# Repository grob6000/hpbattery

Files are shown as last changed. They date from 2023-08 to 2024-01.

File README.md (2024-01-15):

# HP Battery

## UPDATED PROJECT

**Please see my new project page at [github.com/calcpsu/cphp82001](https://github.com/calcpsu/cphp82001)**

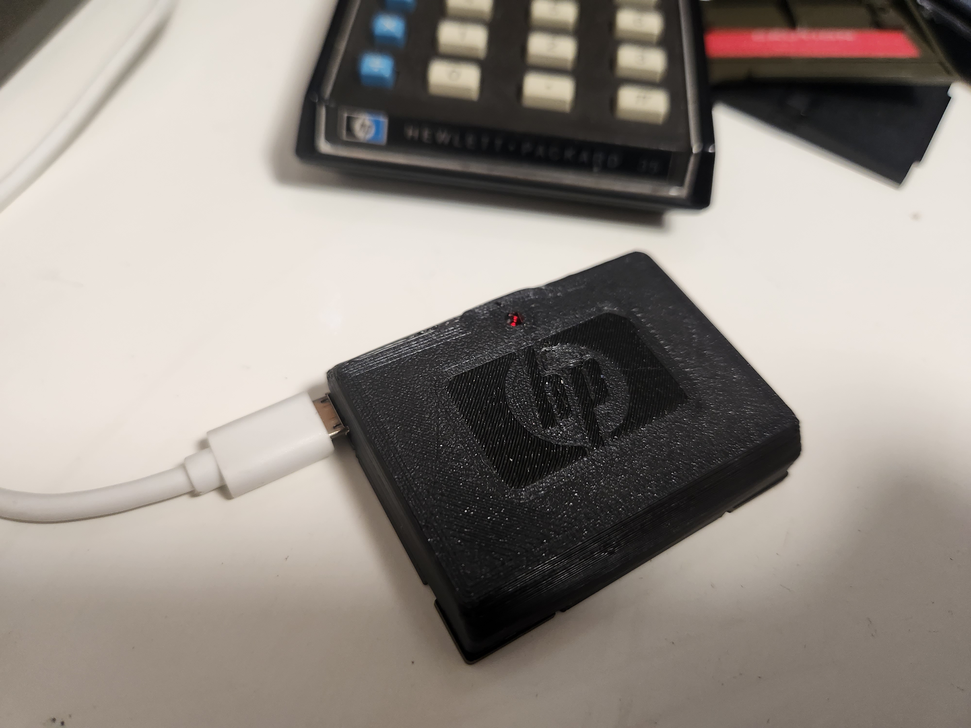
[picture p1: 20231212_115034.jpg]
Photo of prototype battery


A Li-Po battery replacement design for HP35/HP45/HP55/HP65/HP67 calculators. The original batteries had ~ 500mAh capacity, while modern Ni-MH replacements are typically ~1500mAh.

While a higher capacity is not necessarily feasible, Li-Po has the advantage of far reduced self-discharge in comparison to Ni-MH, which is an advantage for an intermittently-used device.

Ni-MH / Ni-CD batteries are notorious for leaking, which is somewhat traded-off against the notoriety of Li-Pos to self-immolate.

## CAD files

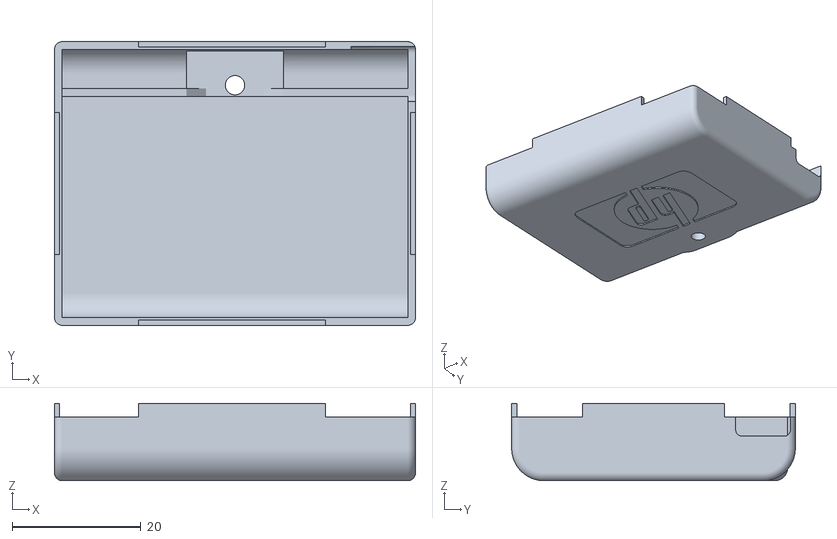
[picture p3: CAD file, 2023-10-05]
hpbatterycase_05_HP.stl
56.0 x 44.0 x 12.0

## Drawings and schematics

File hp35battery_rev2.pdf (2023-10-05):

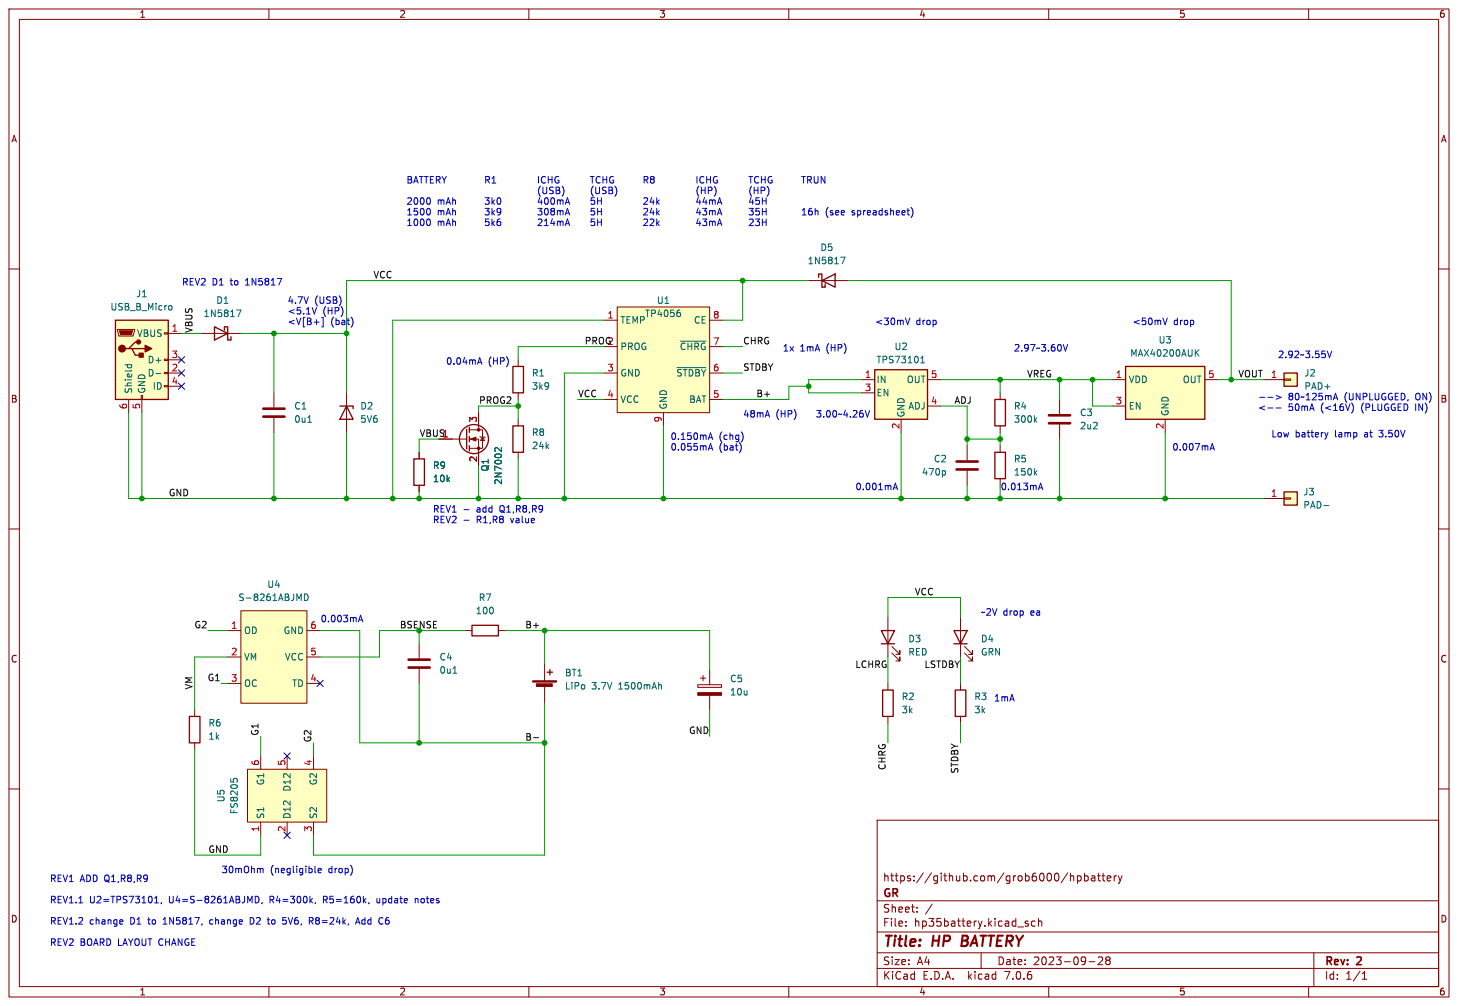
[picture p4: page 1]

BATTERY R1 ICHG TCHG R8 ICHG TCHG TRUN
(USB) (USB) (HP) (HP) 2000 mAh 3k0 400mA 5H 24k 44mA 45H
VREG CHRG
ADJ VCC

Low battery lamp at 3.50V

https://github.com/grob6000/hpbattery
File: hp35battery.kicad_sch Sheet: / GR

Id: 1/1 Title: HP BATTERY

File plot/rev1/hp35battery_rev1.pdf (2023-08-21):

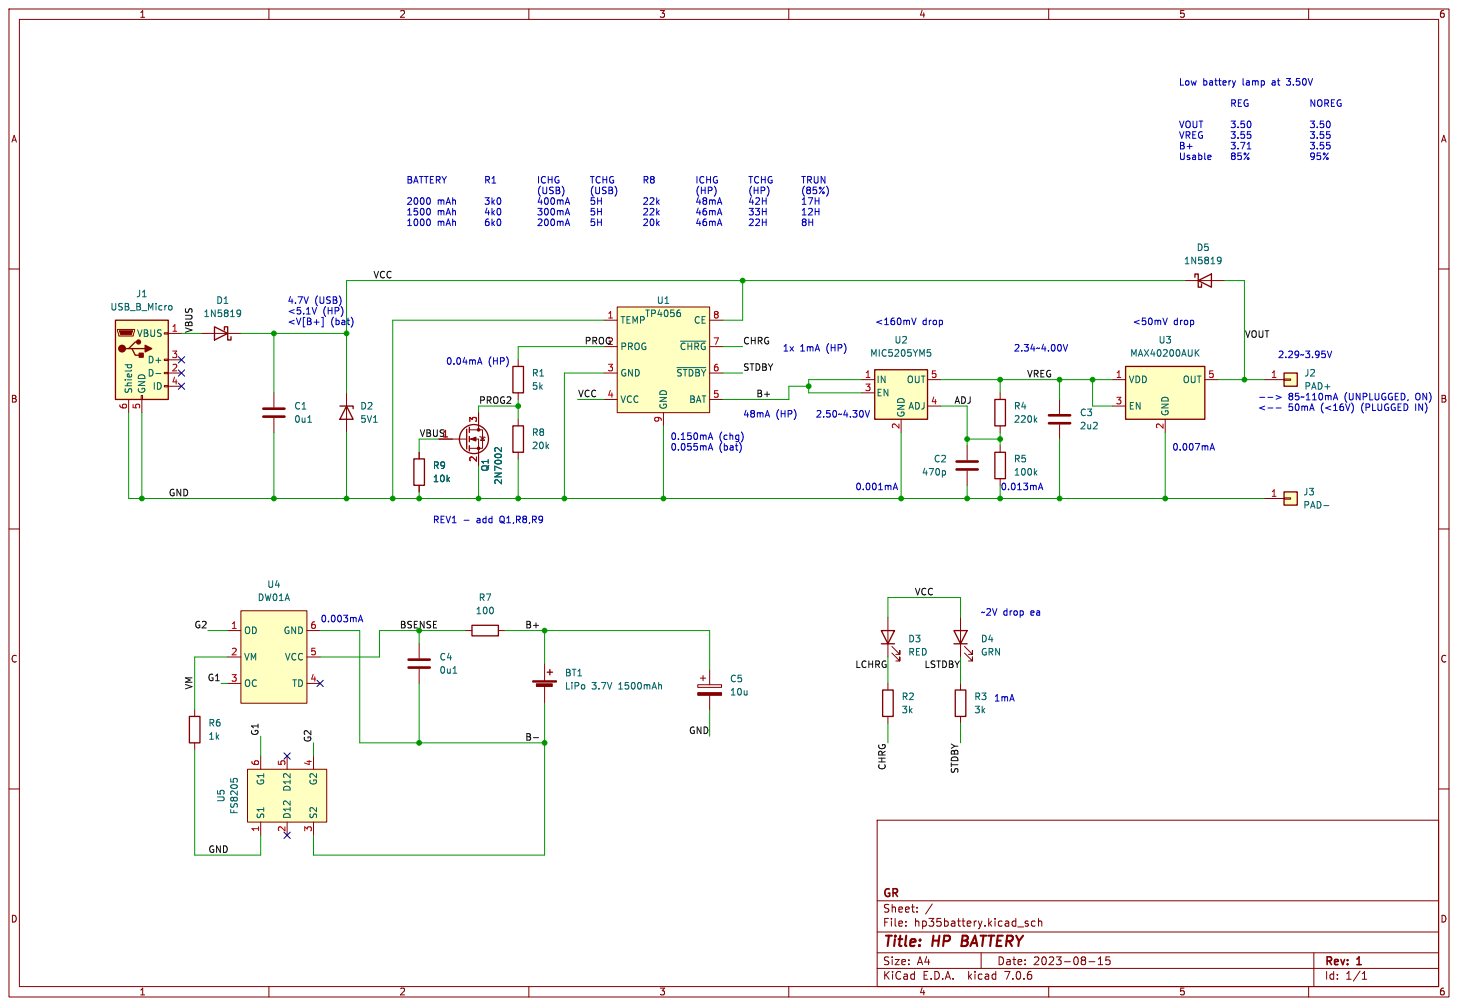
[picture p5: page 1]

Low battery lamp at 3.50V REG NOREG

0.04mA (HP) BATTERY R1 ICHG TCHG R8 ICHG TCHG TRUN
(USB) (USB) (HP) (HP) (85%) 2000 mAh 3k0 400mA 5H 22k 48mA 42H 17H

9 U1 TP4056 D3 RED OD 1 VM 2 OC 3 TD 4 VCC 5 GND 6 U4 DW01A

Id: 1/1 Title: HP BATTERY

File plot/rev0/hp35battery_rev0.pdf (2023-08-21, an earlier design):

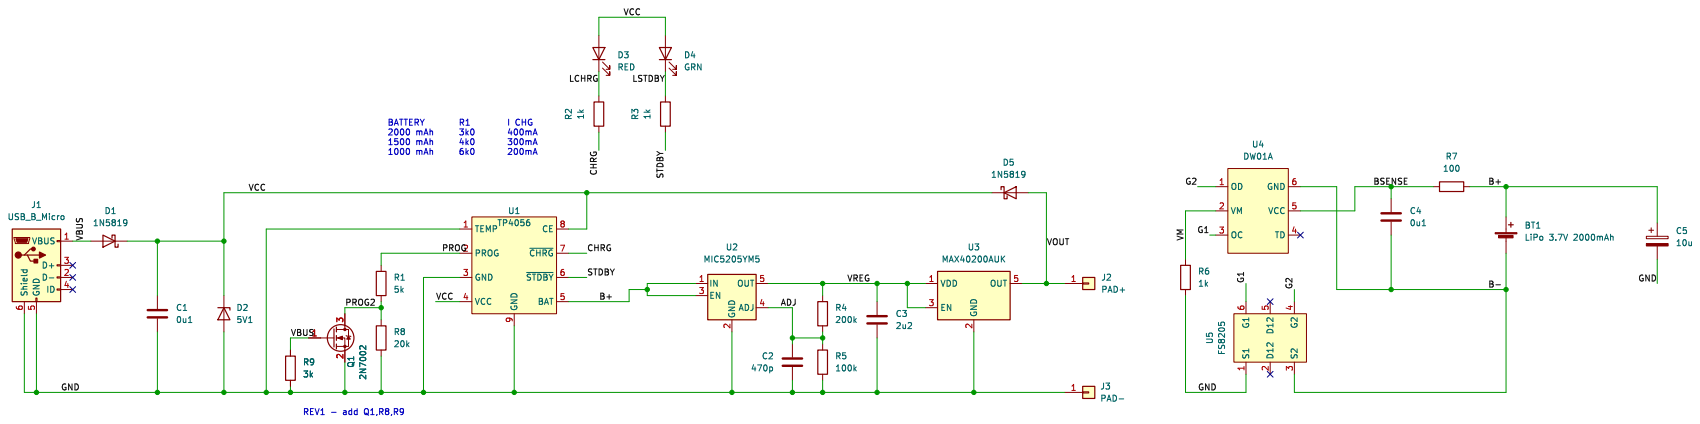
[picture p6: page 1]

Id: 1/1 Title: HP BATTERY

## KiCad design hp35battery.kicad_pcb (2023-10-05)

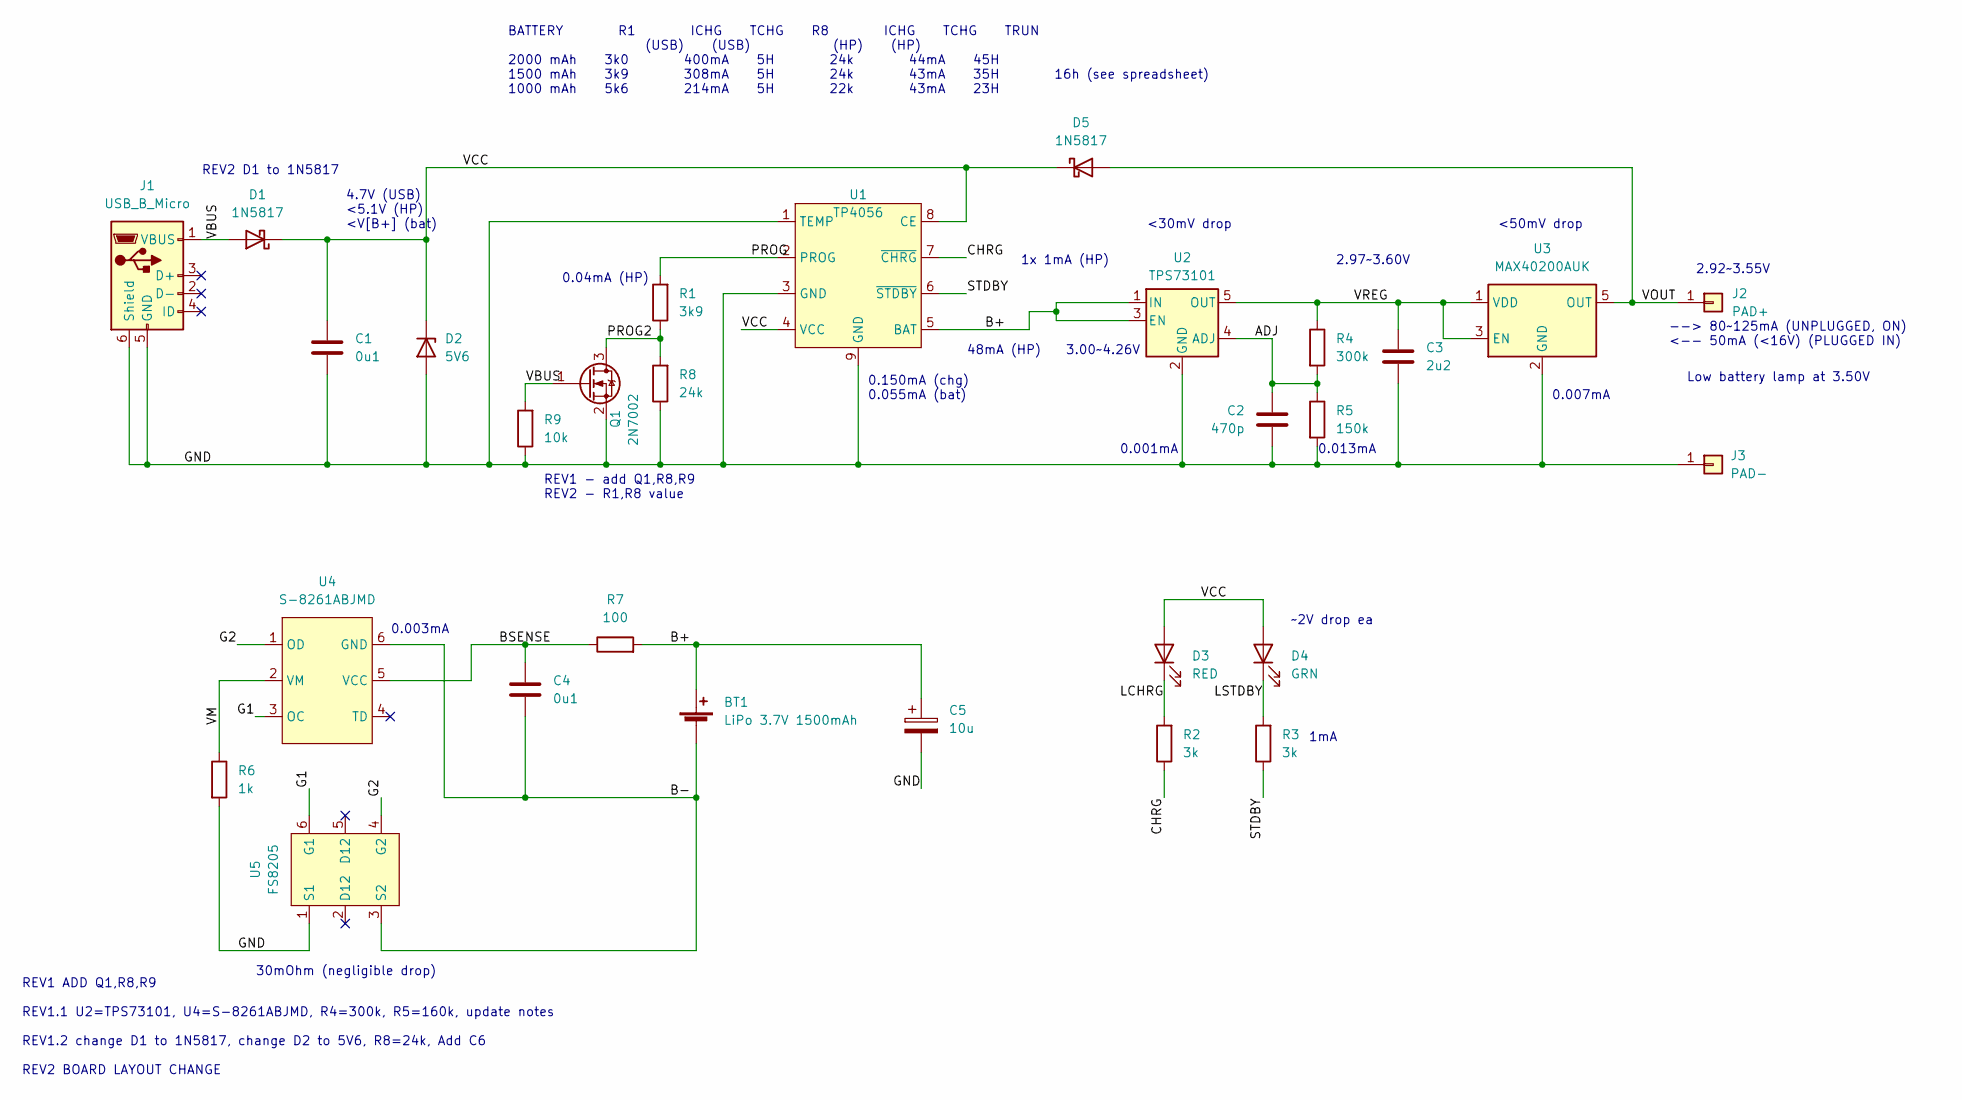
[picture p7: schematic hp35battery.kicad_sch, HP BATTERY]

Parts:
BT1: LiPo 3.7V 1500mAh; PinHeader_1x02_P2.00mm_Vertical
C1, C4: 0u1; C_0805_2012Metric
C2: 470p; C_0805_2012Metric
C3: 2u2; C_0805_2012Metric
C5: 10u; C_1210_3225Metric
D1, D5: 1N5817; D_SOD-123
D2: 5V6; D_SMA
D3: RED; LED_0805_2012Metric
D4: GRN; LED_0805_2012Metric
J1: USB_B_Micro; USB_ALIEX_4LEG
J2: PAD+; PAD_10x15
J3: PAD-; PAD_10x15
Q1: 2N7002; SOT-23
R1: 3k9; R_0805_2012Metric
R2, R3: 3k; R_0805_2012Metric
R4: 300k; R_0805_2012Metric
R5: 150k; R_0805_2012Metric
R6: 1k; R_0805_2012Metric
R7: 100; R_0805_2012Metric
R8: 24k; R_0805_2012Metric
R9: 10k; R_0805_2012Metric
U1: TP4056; TI_SO-PowerPAD-8_ThermalVias
U2: TPS73101; SOT-23-5
U3: MAX40200AUK; SOT-23-5
U4: S-8261ABJMD; SOT-23-6
U5: FS8205; SOT-23-6

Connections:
/ADJ: C2.2, R4.2, R5.1, U2.4 (ADJ)
/B+: BT1.1 (+), C5.1, R7.2, U1.5 (BAT), U2.1 (IN), U2.3 (EN)
/B-: BT1.2 (-), C4.2, U4.6 (GND), U5.3 (S2)
/BSENSE: C4.1, R7.1, U4.5 (VCC)
/CHRG: R2.1, U1.7 (~CHRG)
/G1: U4.3 (OC), U5.6 (G1)
/G2: U4.1 (OD), U5.4 (G2)
/GND: C1.2, C2.1, C3.2, C5.2, D2.2 (A), J1.5 (GND), J1.6 (Shield), J3.1, Q1.2 (S), R5.2, R6.2, R8.1, R9.1, U1.1 (TEMP), U1.3 (GND), U1.9 (GND), U2.2 (GND), U3.2 (GND), U5.1 (S1)
/LCHRG: D3.1 (K), R2.2
/LSTDBY: D4.1 (K), R3.2
/PROG: R1.2, U1.2 (PROG)
/PROG2: Q1.3 (D), R1.1, R8.2
/STDBY: R3.1, U1.6 (~STDBY)
/VBUS: D1.2 (A), J1.1 (VBUS), Q1.1 (G), R9.2
/VCC: C1.1, D1.1 (K), D2.1 (K), D3.2 (A), D4.2 (A), D5.1 (K), U1.4 (VCC), U1.8 (CE)
/VM: R6.1, U4.2 (VM)
/VOUT: D5.2 (A), J2.1, U3.5 (OUT)
/VREG: C3.1, R4.1, U2.5 (OUT), U3.1 (VDD), U3.3 (EN)

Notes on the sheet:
3.00~4.26V
BATTERY R1 ICHG TCHG R8 ICHG TCHG TRUN (USB) (USB) (HP) (HP) 2000 mAh 3k0 400mA 5H 24k 44mA 45H 1500 mAh 3k9 308mA 5H 24k 43mA 35H 16h (see spreadsheet) 1000 mAh 5k6 214mA 5H 22k 43mA 23H
--> 80~125mA (UNPLUGGED, ON) <-- 50mA (<16V) (PLUGGED IN)
0.001mA
0.007mA
4.7V (USB) <5.1V (HP) <V[B+] (bat)
2.97~3.60V
0.003mA
~2V drop ea
<30mV drop
1mA
<50mV drop
REV2 D1 to 1N5817
2.92~3.55V
REV1 - add Q1,R8,R9 REV2 - R1,R8 value
0.013mA
48mA (HP)
30mOhm (negligible drop)
0.04mA (HP)
1x 1mA (HP)
0.150mA (chg) 0.055mA (bat)
REV1 ADD Q1,R8,R9 REV1.1 U2=TPS73101, U4=S-8261ABJMD, R4=300k, R5=160k, update notes REV1.2 change D1 to 1N5817, change D2 to 5V6, R8=24k, Add C6 REV2 BOARD LAYOUT CHANGE
Low battery lamp at 3.50V

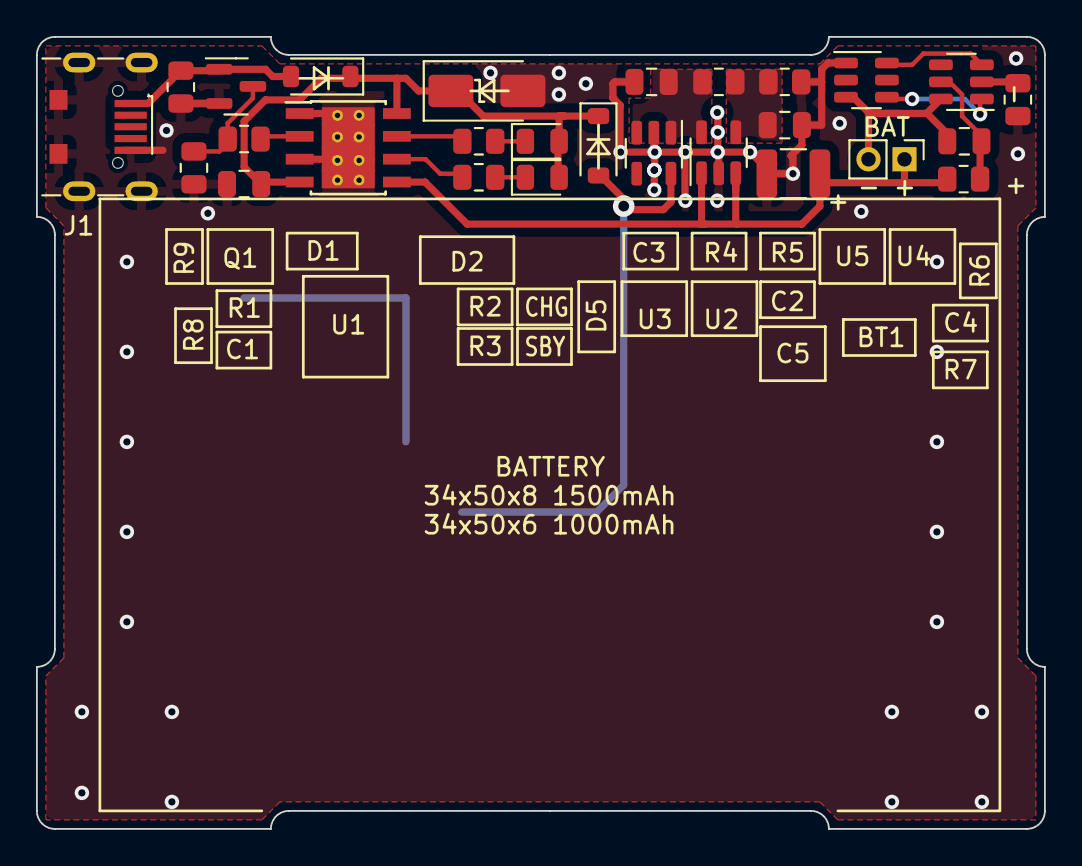
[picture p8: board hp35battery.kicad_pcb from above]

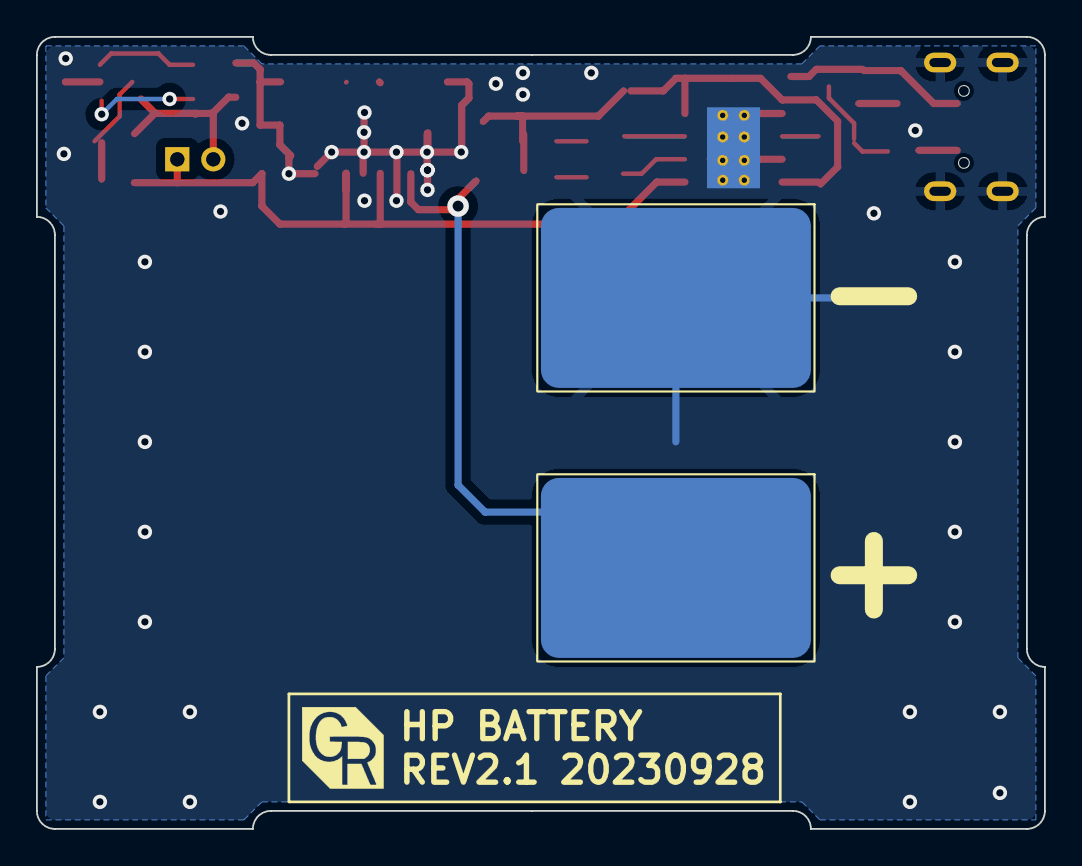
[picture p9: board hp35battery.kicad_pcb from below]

Board: 2 copper layers, 56.0 x 44.0 mm, 29 parts (2 on the bottom side), 18 nets.

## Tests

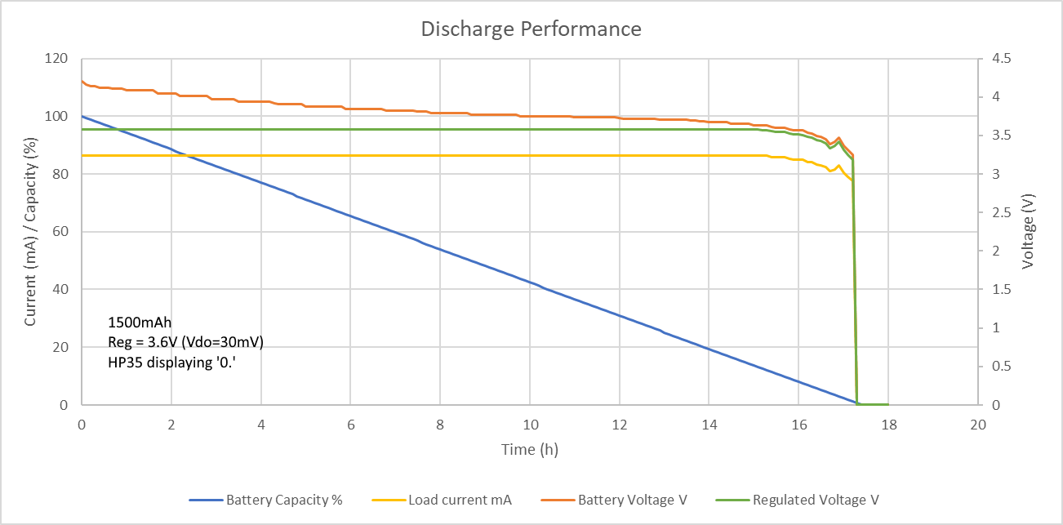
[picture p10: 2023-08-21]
dischargeperformance_3v6.png

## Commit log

2023-08-21 Calc updates
    [hpbattery.xlsx]
2023-08-21 Further calc and schematic update
    [hp35battery.kicad_sch, hpbattery.xlsx]
2023-08-21 Schematic plot
    [hp35battery.kicad_sch]
2023-10-05 Rev 2.1
    Updated to:
    * Fit HP67 (reduced length/width, contact size/position)
    * Board shape has 1mm recess on all four sides (better case design)
    * All components fit on top side
    * V2.1: slightly better thermal arrangement for regulator
    [hp35battery.kicad_pcb, hp35battery.kicad_sch, hpbatterycase_05_HP.stl]
